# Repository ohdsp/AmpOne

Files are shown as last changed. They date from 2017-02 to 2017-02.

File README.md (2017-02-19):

# [Open Hardware DSP Platform](http://www.ohdsp.org)
## AmpOne
### Revision 1.0

---
# README
### Disclaimer
Copyright Paul Janicki 2017

Licensed under the TAPR Open Hardware License (www.tapr.org/OHL)

This documentation is distributed WITHOUT ANY EXPRESS OR IMPLIED WARRANTY, INCLUDING OF MERCHANTABILITY, SATISFACTORY QUALITY AND FITNESS FOR A PARTICULAR PURPOSE.

### What is this repository?

**Quick summary**

This is Open Hardware DSP Platform AmpOne Module. 

This is a TDA7498 or TDA7492 based Class D amplifier PCB design with up to two ICs fitted allowing for 4 channels of audio.

This repository contains the KiCad design files, manufacturing Gerber/drill files, PDF/drawing files, and relevant documenation for this board.

### What is the project folder structure?
Most folder names are self explanatory. Starting from the top level: \
*AmpOne*
+ *Bill of Materials*  - This contains the bill of materials in CVS, LibreOffice Calc and XML formats
+ *Drawings*  - This contains PDF and SVG outputs of schematic and PCB files
+ *Gerbers* - This contains the PCB Gerbers and drill drawings for manufacture, there is also a zip file ready to send to most manufacturers
+ *KiCad* - This contains the original KiCad schematic and PCB design files
+ *Pick-Place and Stencil* - This contains the pick and place file for automated placement of PCB components and the pasate/stencil layer to make a solder paste stencil 

### How do I get set up?

**Summary of set up**

1. Set your self up a directory on a local disk, something simple will make life easier (eg C:\Electronics on Windows as used here), but anywhere will do just fine.
2. Download the Kicad-Libs from [https://github.com/ohdsp/KiCad-Libs](https://github.com/ohdsp/KiCad-Libs) and place in C:\Electronics\Kicad-Libs (or your chosen folder) 
3. Create a OHDSP subdirectory in C:\Electronics (so C:\Electronics\OHDSP)
3. Download this project to C:\Electronics\OHDSP\AmpOne
4. Fire up Kicad
5. Open the main project file C:\Electronics\OHDSP\AmpOne\KiCad\AmpOne.pro
6. (Optional) Setup Pcbnew component library as below.
7. Do as you wish with the project, just keep it under TAPR Open Hardware License

Make sure your git setup doesn't exclude files used in the project (like .LIB files) or things may go wrong down the line.

**KiCad Library Configuration**

Note that you need to setup a Pcbnew library, but the eeschema libraries should work without any changes if you followed the instructions above.

To setup Pcbnew libraries:

In Pcbnew go to Preferences -> Footprint Libraries Manager. Under Global Libraries tab in the top list check if there is a nickname "MyKiCadLibs-Footprints" (usually at the end of the list). If there is but it points to the wrong place then change the Library Path to point to MyKiCadLibs-Footprints (eg C:\Electronics\KiCad-Libs\MyKiCadLibs-Footprints.pretty) folder for your setup. If this is missing you can use "Append with Wizard", choose "Files on my computer", click next, browse to library location (eg C:\Electronics\KiCad-Libs\MyKiCadLibs-Footprints.pretty) and select the folder MyKiCadLibs-Footprints.pretty, click next, check the Status column states OK and the Format is KiCad (if not re-download the library) and click next, then select "To global library configuration..." and click Finish.

To setup eeschema component libraries:
Either from KiCad project window go to Tools -> Run Library Editor OR under eeschema, go to Tools -> Library Editor. Then Preferences -> Component Libraries.

The top section "Component Library Files" should ideally contain only two libraries, the "power" library that ships with KiCad and "MyKiCadLibs-Lib" available from above. To setup MyKiCadLibs-Lib as a relative path under the "User defined search path" click add. Browse to the location of KiCad-Libs you download above (eg C:\Electronics\KiCad-Libs) and click "Select Folder". Say yes to add a relative path. Under component library files click add, browse to the KiCad-libs again (eg C:\Electronics\KiCad-Libs), select file "MyKiCadLibs-Lib.lib" and click open. MyKiCadLibs-lib should appear in the component library list with no path as it will be using the user defined search path set in the box below.

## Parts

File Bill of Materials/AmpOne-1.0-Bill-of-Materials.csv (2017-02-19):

Reference | Quantity | Footprint | Value | Voltage | Type | Description | Tolerance | Size | Power | Current
C101 C301 C325 C331 C357 | 5 | CAP-TH-D12.5mmP5mm | 560u | '63V | ' | '560uF 63V High ripple current long life, eg Panasonic FR EEUFR1J561L | ' | 'Pitch 5mm, Diameter 12.5mm | ' | '
C102 C302 C326 C332 C358 | 5 | SMD-0805 | 4u7 | '50V | 'X5R | 'Ceramic capacitor | '10% | '0805 | ' | '
C103 C303 C306 C313 C321 C323 C324 C327 C330 C333 C335 C339 C346 C354 C356 C359 C362 | 17 | SMD-0805 | 100n | '50V | 'X7R | 'Ceramic capacitor | '10% | '0805 | ' | '
C203 C205 C210 C212 C217 C219 C224 C226 | 8 | CAP_TH_5mm_W3.5mm | 100n | '63V | 'MKT | 'Polyester film capacitor | '5% | '5mm | ' | '
C202 C204 C206 C209 C211 C213 C216 C218 C220 C223 C225 C227 | 12 | SMD-0805 | 1n | '50V | 'C0G | 'Ceramic capacitor | '5% | '0805 | ' | '
C201 C207 C208 C214 C215 C221 C222 C228 | 8 | CAP-TH-D6.3mmP2.5mm | 10u | '63V | ' | 'High quality capacitor, eg Panasonic FC | ' | 'Pitch 2.5mm, Diameter 6.3mm | ' | '
C304 C305 C307 C308 C309 C310 C312 C316 C317 C318 C319 C320 C328 C329 C334 C338 C340 C341 C342 C343 C345 C349 C350 C351 C352 C353 C360 C361 | 28 | CAP_TH_P5mm_W3.5mm_L7.3mm | 220n | '100V | 'MKT | 'Epcos B32529C1224 or Kemet R82EC3220Z370J – See schematic for detailed part information for TDA7492/TDA7498/TDA7498E | '5% | 'Size | ' | '
C311 C315 C344 C348 | 4 | CAP_TH_5mm | 330p | '1kV | 'FKP | 'Wima FKP2O103301D00J | '5% | '5mm | ' | '
C314 C322 C347 C355 | 4 | SMD-0805 | 10u | '10V | 'X7R | 'Ceramic capacitor | '10% | '0805 | ' | '
C336 C337 | 2 | SMD-0805 | 2u2 | '10v | 'X5R | 'Ceramic capacitor | '20% | '0805 | ' | '
D301 | 1 | DIODE-SOD-123 | MMSZ5225BT1G | '3V | ' | 'SOD-123 Zener Diode | ' | ' | '500mW | '
L301 L302 L303 L304 L305 L306 L307 L308 | 8 | IND-TH-PCV-0-223-10L | PCV-0-223-10L | ' | ' | 'Coilcraft PCV-0-223-10L - See schematic for detailed part information for TDA7492/TDA7498/TDA7498E | ' | 'Size | ' | '13A
P201 | 1 | CONN_DIL_2X10_BOX_1MM | CONN_02X10 | ' | ' | '2x10 2.54mm pitch box header | ' | ' | ' | '
P104 P301 P302 P306 P307 | 5 | CONN-SCREW-2WAY-7.5mm-7.62mm | CONN_2x1 | ' | ' | '7.5mm/7.62mm Pitch 2 Way Screw Terminal | ' | ' | ' | '
P303 P304 P305 P308 P309 P310 P311 | 7 | CONN_SIL_2_1MM | CONN_2x1 | ' | ' | '2x1 Pin Header 2.54mm | ' | ' | ' | '
R202 R203 R206 R207 R210 R211 R214 R215 | 8 | SMD-1206 | 100k | ' | ' | 'MELF0204 1% =>250mW or 1206 1% =>250mW | '1% | '1206 | '250mW | '
R201 R204 R205 R208 R209 R212 R213 R216 | 8 | SMD-1206 | 100 | ' | ' | 'MELF0204 1% =>250mW or 1206 1% =>250mW | '1% | '1206 | '250mW | '
R301 R303 R307 R309 R317 R319 R323 R324 | 8 | SMD_MELF_0207 | 8R2 | ' | ' | 'High Power 1W MELF 0207 | '5% | 'Axial | '1W | '
R302 R306 R318 R322 | 4 | SMD_MELF_0207 | 22 | ' | ' | 'High Power 1W MELF 0207 | '5% | 'Axial | '1W | '
R304 R305 R320 R321 | 4 | SMD-0805 | 10k | ' | ' | 'Thick or thin film resistor | '1% | '0805 | '100mW | '
R308 | 1 | SMD-0805 | 39k | ' | ' | 'Thick or thin film resistor | '1% | '0805 | '100mW | '
R310 | 1 | SMD-2512 | 1k8 | ' | ' | 'High Power 2512 Resistor | '1% | '2512 | '2W | '
R311 | 1 | SMD-0805 | 0 | ' | ' | 'Thick or thin film resistor | '1% | '0805 | '100mW | '
R312 | 1 | SMD-0805 | 47k | ' | ' | 'Thick or thin film resistor | '1% | '0805 | '100mW | '
R313 R315 | 2 | SMD-0805 | 1k | ' | ' | 'Thick or thin film resistor | '1% | '0805 | '100mW | '
R314 | 1 | SMD-0805 | 220k | ' | ' | 'Thick or thin film resistor | '1% | '0805 | '100mW | '
R316 | 1 | SMD-0805 | 33 | ' | ' | 'Thick or thin film resistor | '1% | '0805 | '100mW | '
U301 U302 | 2 | IC-PowerSSO-36-EPU | TDA7498 | ' | ' | 'TDA7492/TDA7498 - See schematic for details | ' | ' | ' | '

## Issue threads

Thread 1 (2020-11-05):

KiCad version 5

tamasharasztosi, 2020-11-05:
Hello!
Great work!
Do you think it's possible or not to convert this project into new KiCad 5?
I have problems with the schematic symbols when I open it.

Thank you!

ohdsp, 2020-11-08:
Hi,

Yes they can all be converted, I still do it, however with 5.1.x versions as soon as you open the project file (v4) it seems to remove all the library information (LibDir=...) from the .pro file and save it with it missing.

When you when try and open the schematic it cannot find any symbols to convert it to a v5 project with. Seems to be because the latest versions put the library location in a separate sym-lib-table file.

Last project I converted I ended up opening the project files in notepad++ and re-adding the library information, which allowed it to convert properly.

This project won't be touched by me for a while, I have all the parts to build several up but haven't got around to it yet. PCB needs an update as some of the filter resistors should be 5W through holes and not SMD parts.

Cheers.

________________________________
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

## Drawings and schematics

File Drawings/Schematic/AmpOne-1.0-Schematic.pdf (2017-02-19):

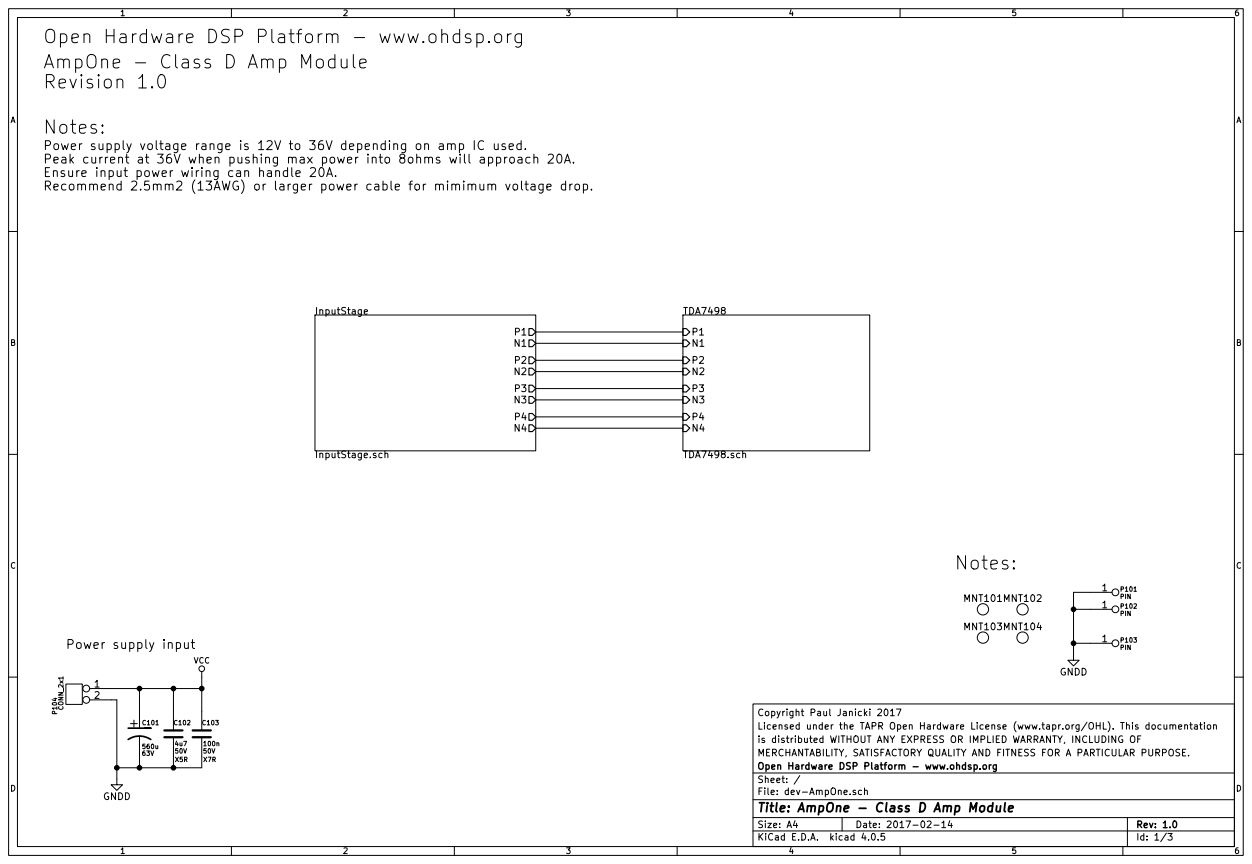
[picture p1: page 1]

Open Hardware DSP Platform - www.ohdsp.org
AmpOne - Class D Amp Module
Revision 1.0

Notes:
Power supply voltage range is 12V to 36V depending on amp IC used.
Peak current at 36V when pushing max power into 8ohms will approach 20A.
Ensure input power wiring can handle 20A.
Recommend 2.5mm2 (13AWG) or larger power cable for mimimum voltage drop.

Copyright Paul Janicki 2017
Licensed under the TAPR Open Hardware License (www.tapr.org/OHL). This documentation
is distributed WITHOUT ANY EXPRESS OR IMPLIED WARRANTY, INCLUDING OF
MERCHANTABILITY, SATISFACTORY QUALITY AND FITNESS FOR A PARTICULAR PURPOSE.
File: dev-AmpOne.sch Sheet: / Open Hardware DSP Platform - www.ohdsp.org

Id: 1/3 Title: AmpOne - Class D Amp Module

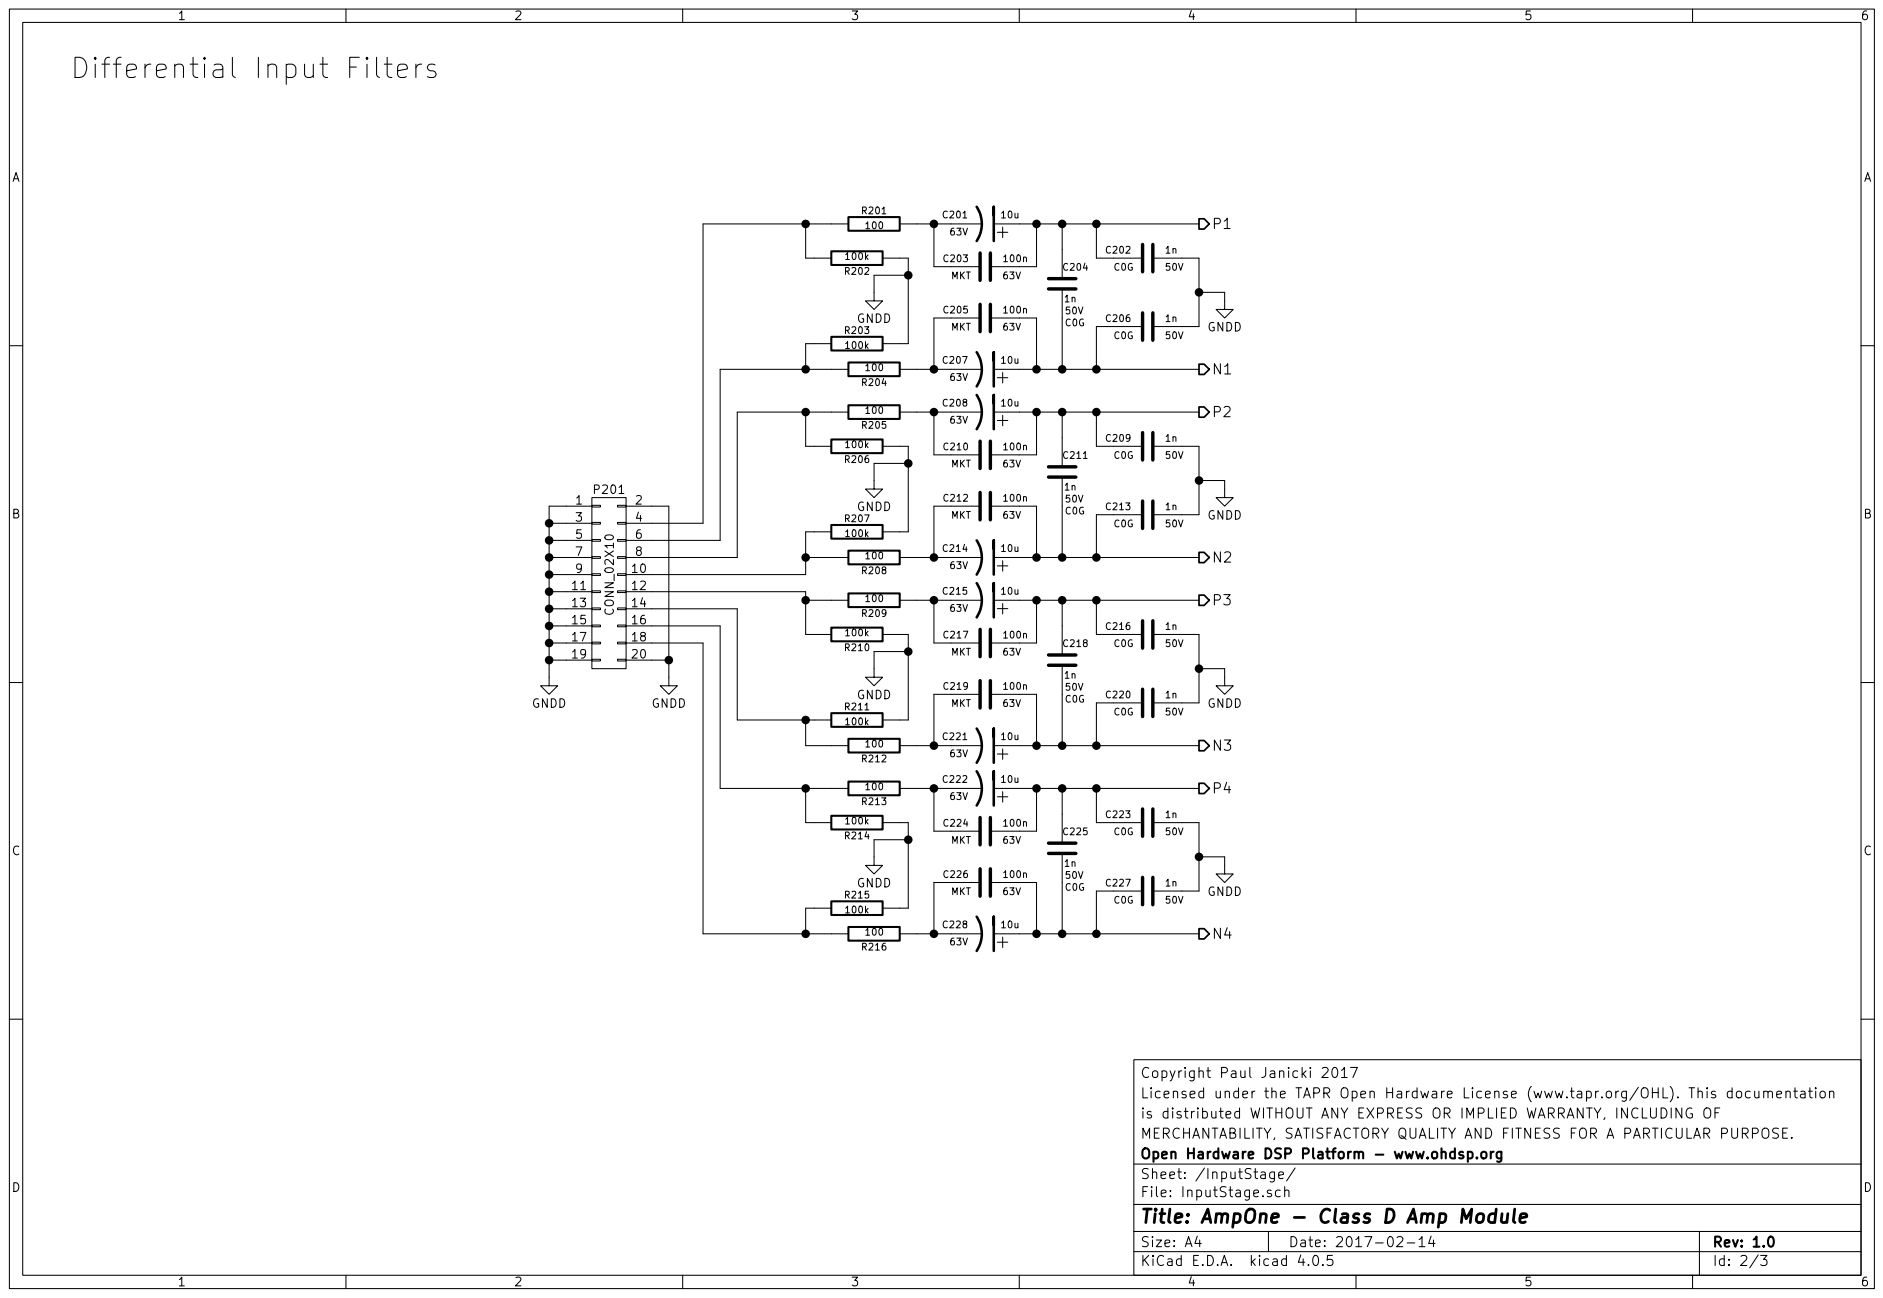
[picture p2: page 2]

9 | 10
11 | 12
13 | 14
15 | 16
17 | 18

Copyright Paul Janicki 2017
Licensed under the TAPR Open Hardware License (www.tapr.org/OHL). This documentation
is distributed WITHOUT ANY EXPRESS OR IMPLIED WARRANTY, INCLUDING OF
MERCHANTABILITY, SATISFACTORY QUALITY AND FITNESS FOR A PARTICULAR PURPOSE.
Open Hardware DSP Platform - www.ohdsp.org
Sheet: /InputStage/
File: InputStage.sch
Id: 2/3 Title: AmpOne - Class D Amp Module

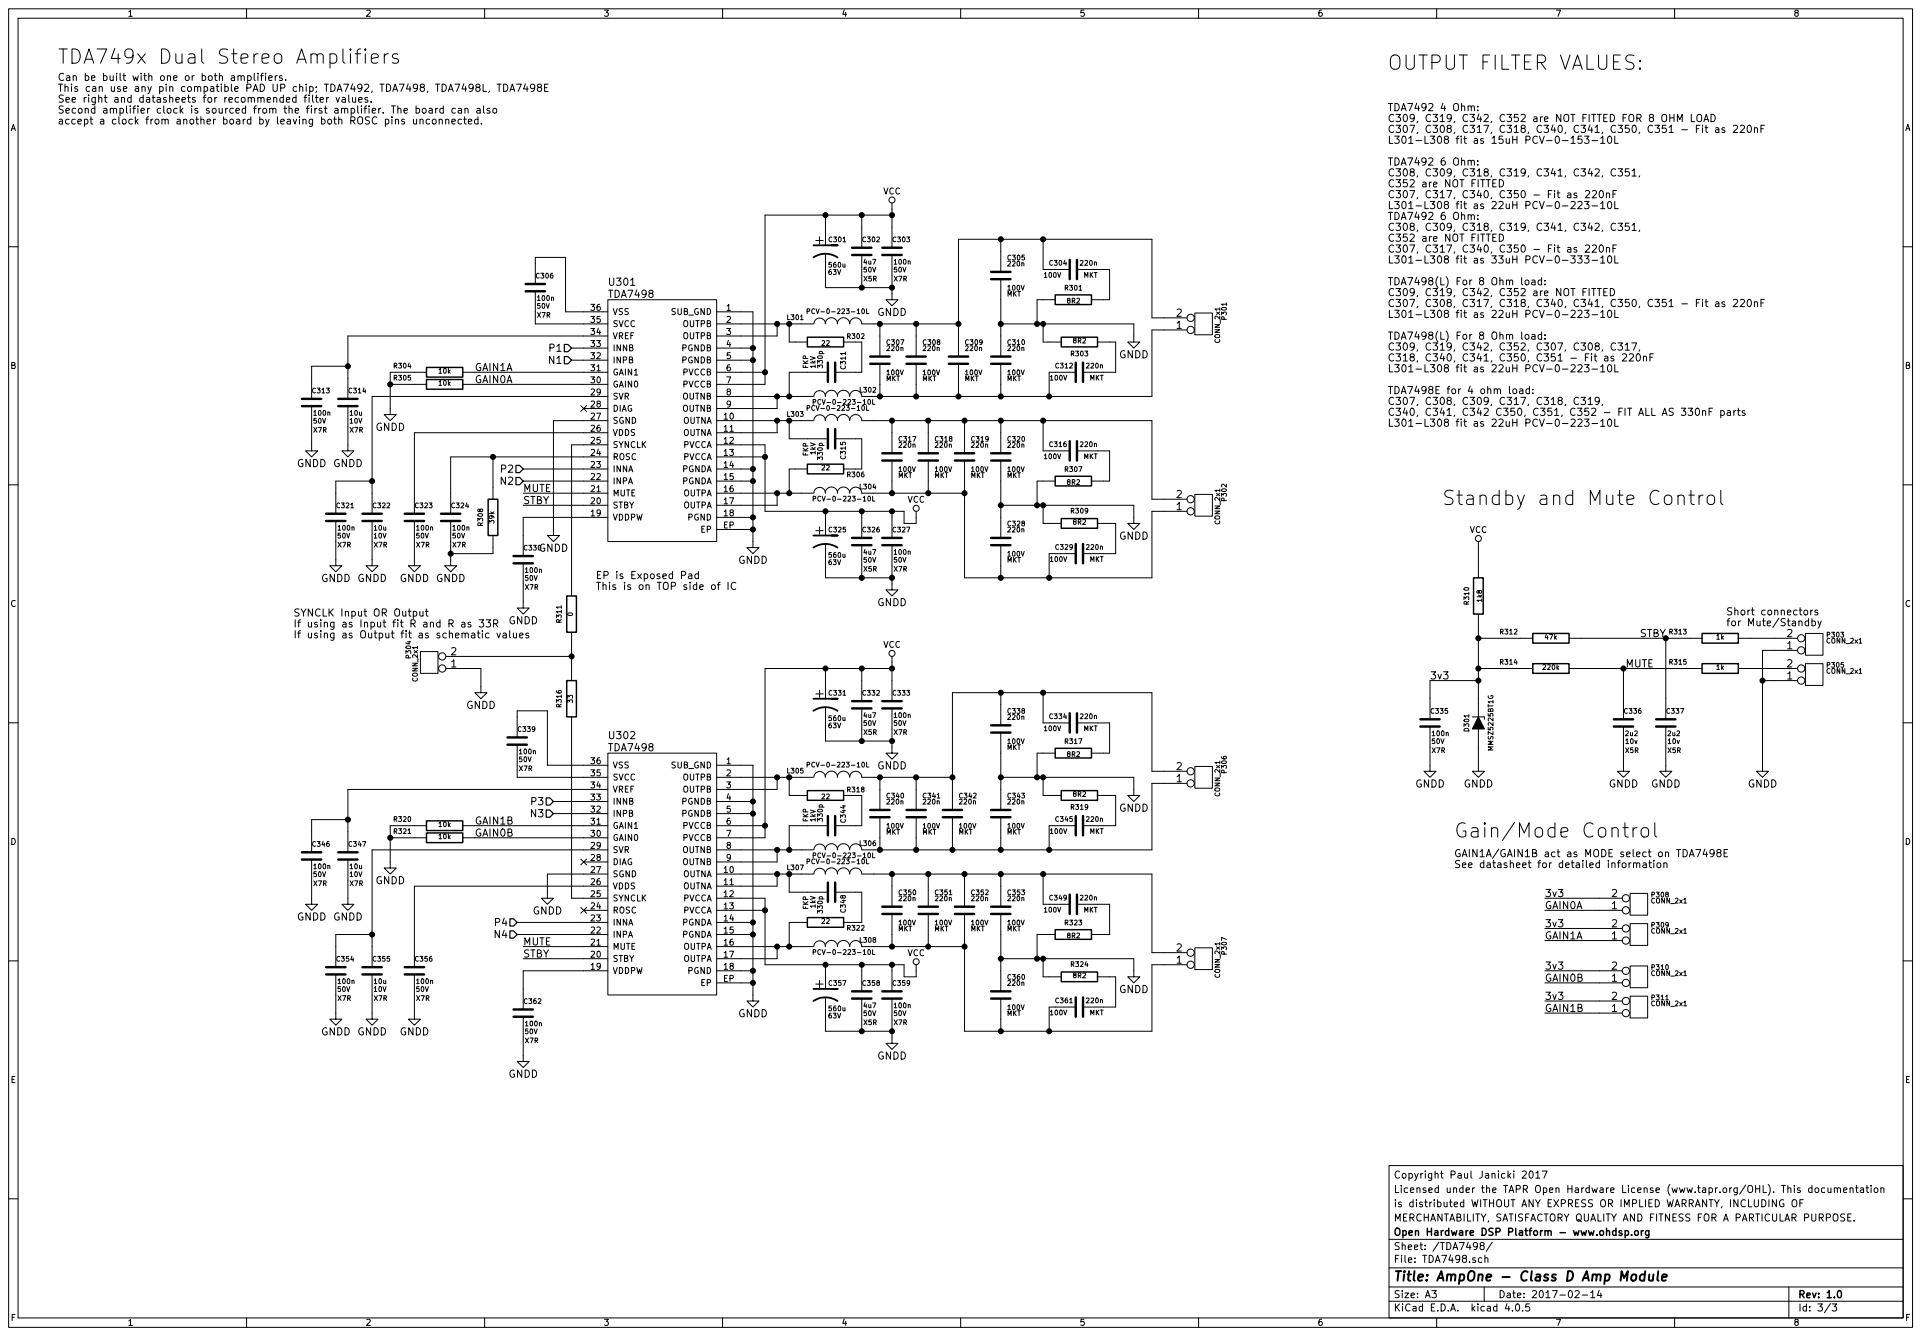
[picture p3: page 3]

Can be built with one or both amplifiers.
This can use any pin compatible PAD UP chip; TDA7492, TDA7498, TDA7498L, TDA7498E
See right and datasheets for recommended filter values.
Second amplifier clock is sourced from the first amplifier. The board can also
accept a clock from another board by leaving both ROSC pins unconnected.

TDA7492 4 Ohm:
C309, C319, C342, C352 are NOT FITTED FOR 8 OHM LOAD
C307, C308, C317, C318, C340, C341, C350, C351 - Fit as 220nF
L301-L308 fit as 15uH PCV-0-153-10L
TDA7492 6 Ohm:
C352 are NOT FITTED
C307, C317, C340, C350 - Fit as 220nF
L301-L308 fit as 22uH PCV-0-223-10L
L301-L308 fit as 33uH PCV-0-333-10L
TDA7498(L) For 8 Ohm load:
C309, C319, C342, C352 are NOT FITTED
C318, C340, C341, C350, C351 - Fit as 220nF
L301-L308 fit as 22uH PCV-0-223-10L TDA7498E for 4 ohm load: C307, C308, C309, C317, C318, C319,

C340, C341, C342 C350, C351, C352 - FIT ALL AS 330nF parts

INNA 23
INPA 22

EP is Exposed Pad
This is on TOP side of IC

If using as Input fit R and R as 33R
If using as Output fit as schematic values

GAIN1A/GAIN1B act as MODE select on TDA7498E

Copyright Paul Janicki 2017
Licensed under the TAPR Open Hardware License (www.tapr.org/OHL). This documentation
is distributed WITHOUT ANY EXPRESS OR IMPLIED WARRANTY, INCLUDING OF
MERCHANTABILITY, SATISFACTORY QUALITY AND FITNESS FOR A PARTICULAR PURPOSE.
File: TDA7498.sch Sheet: /TDA7498/ Open Hardware DSP Platform - www.ohdsp.org

Id: 3/3 Title: AmpOne - Class D Amp Module

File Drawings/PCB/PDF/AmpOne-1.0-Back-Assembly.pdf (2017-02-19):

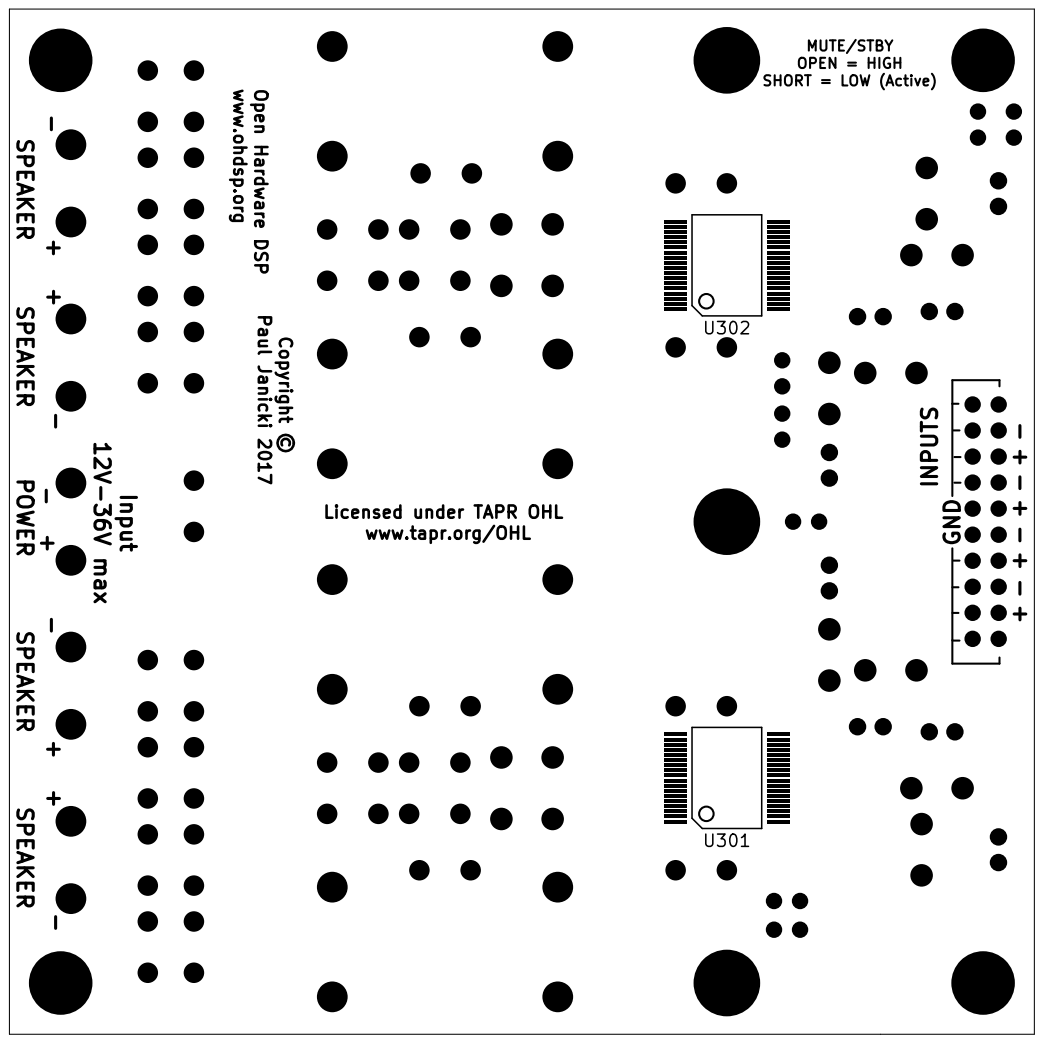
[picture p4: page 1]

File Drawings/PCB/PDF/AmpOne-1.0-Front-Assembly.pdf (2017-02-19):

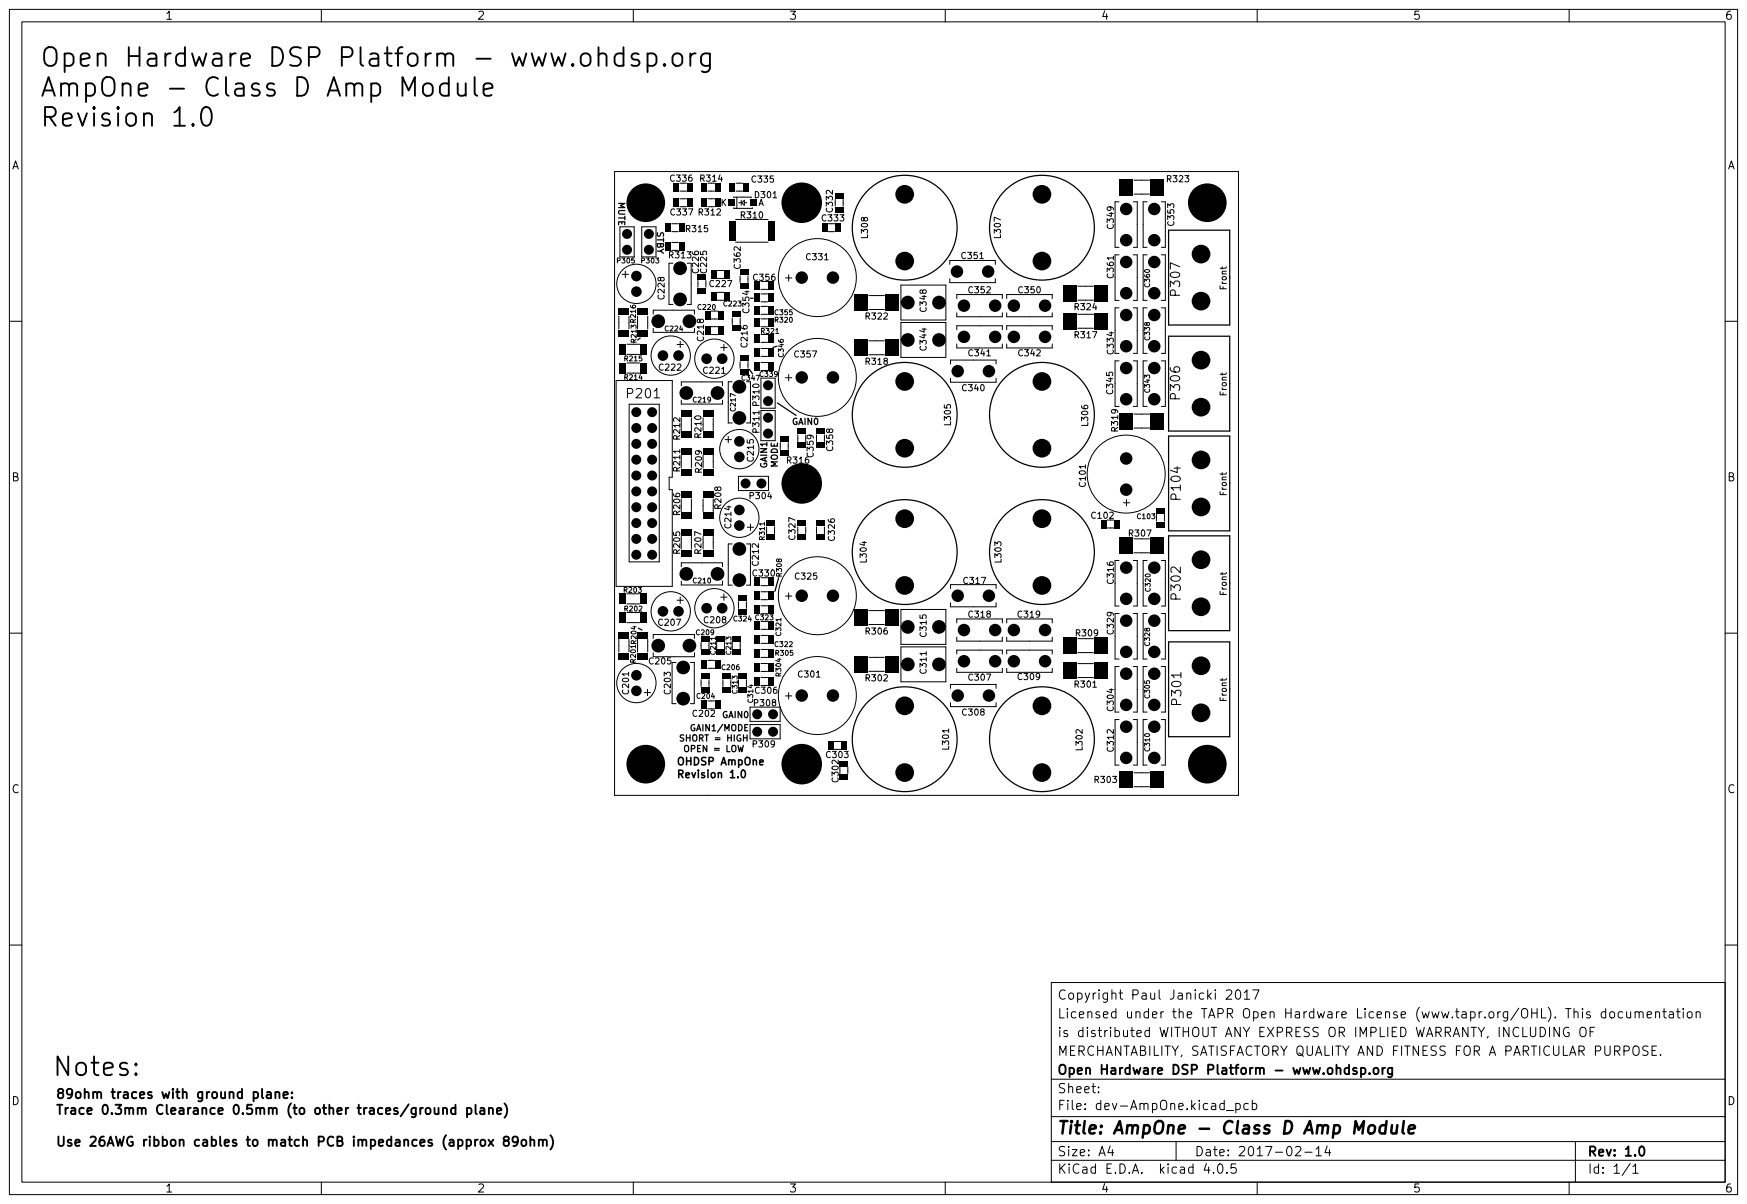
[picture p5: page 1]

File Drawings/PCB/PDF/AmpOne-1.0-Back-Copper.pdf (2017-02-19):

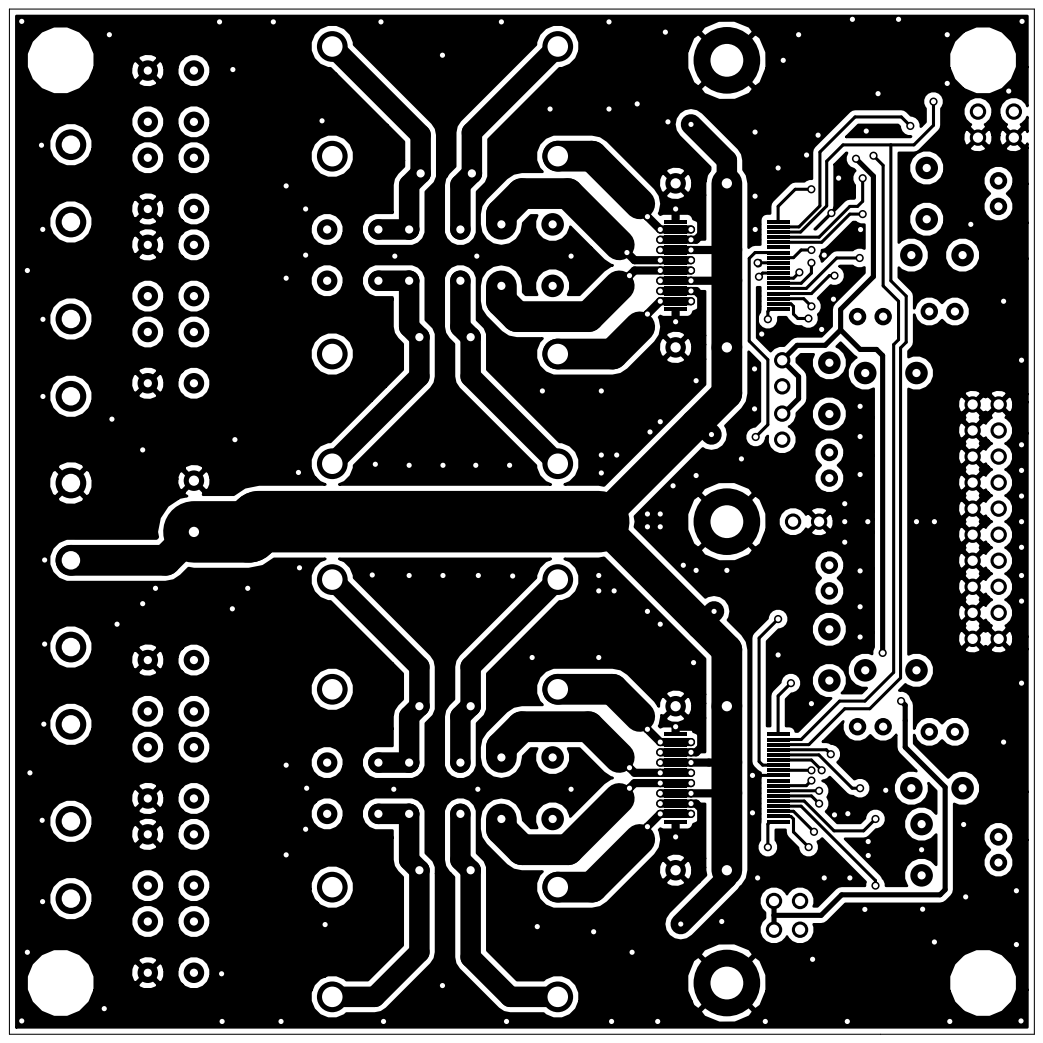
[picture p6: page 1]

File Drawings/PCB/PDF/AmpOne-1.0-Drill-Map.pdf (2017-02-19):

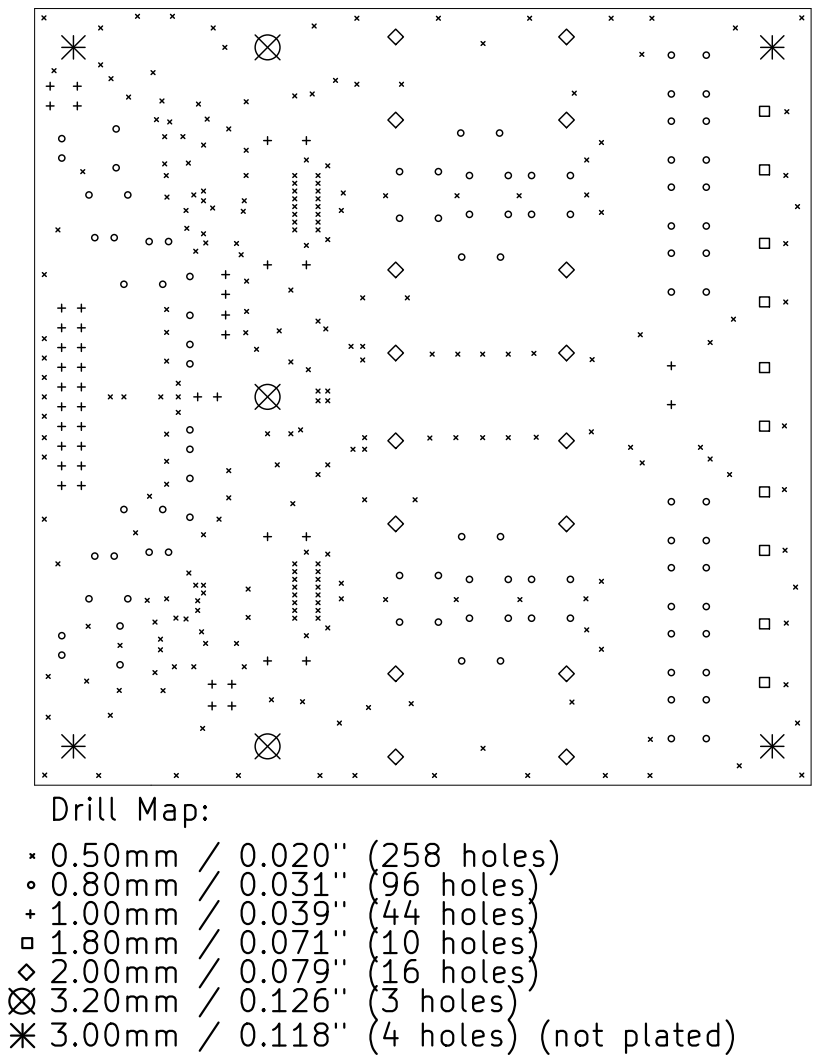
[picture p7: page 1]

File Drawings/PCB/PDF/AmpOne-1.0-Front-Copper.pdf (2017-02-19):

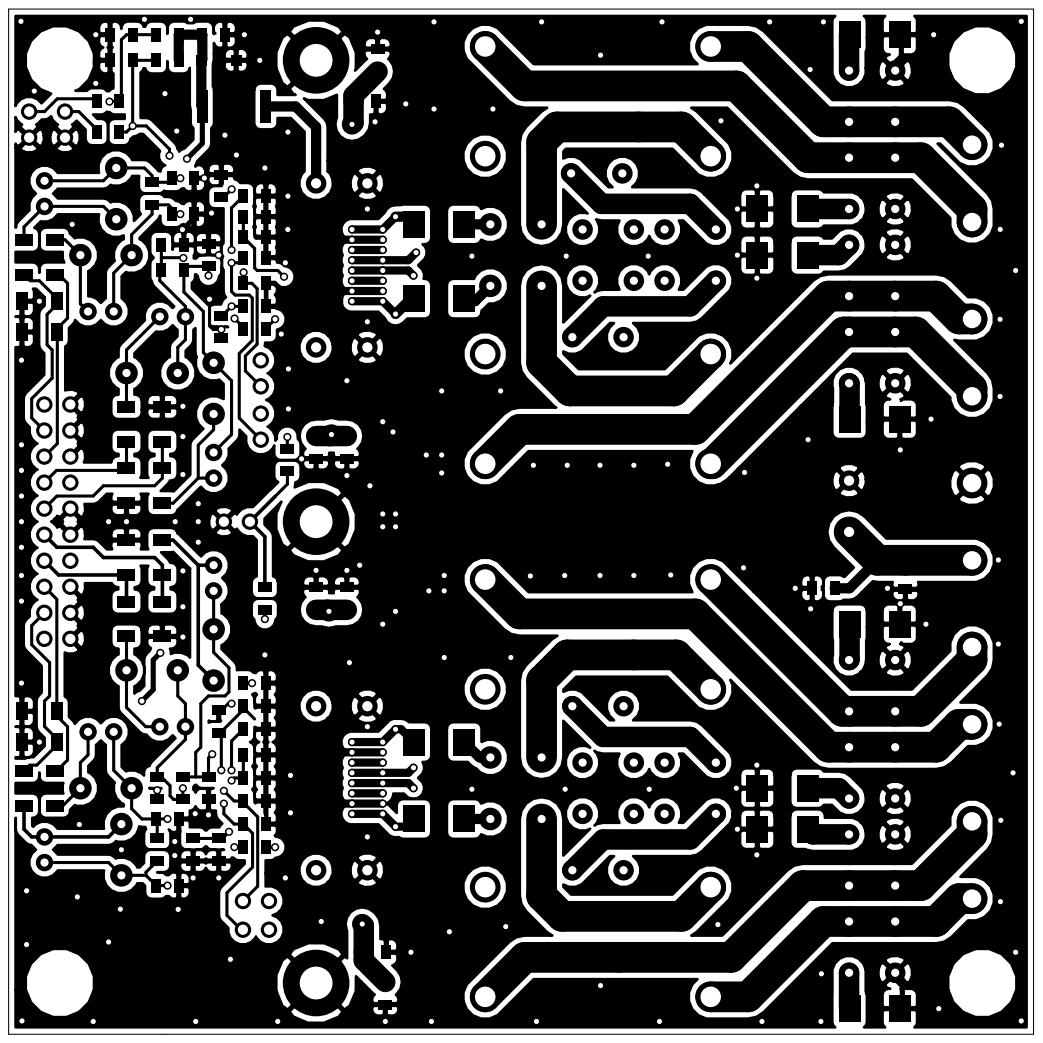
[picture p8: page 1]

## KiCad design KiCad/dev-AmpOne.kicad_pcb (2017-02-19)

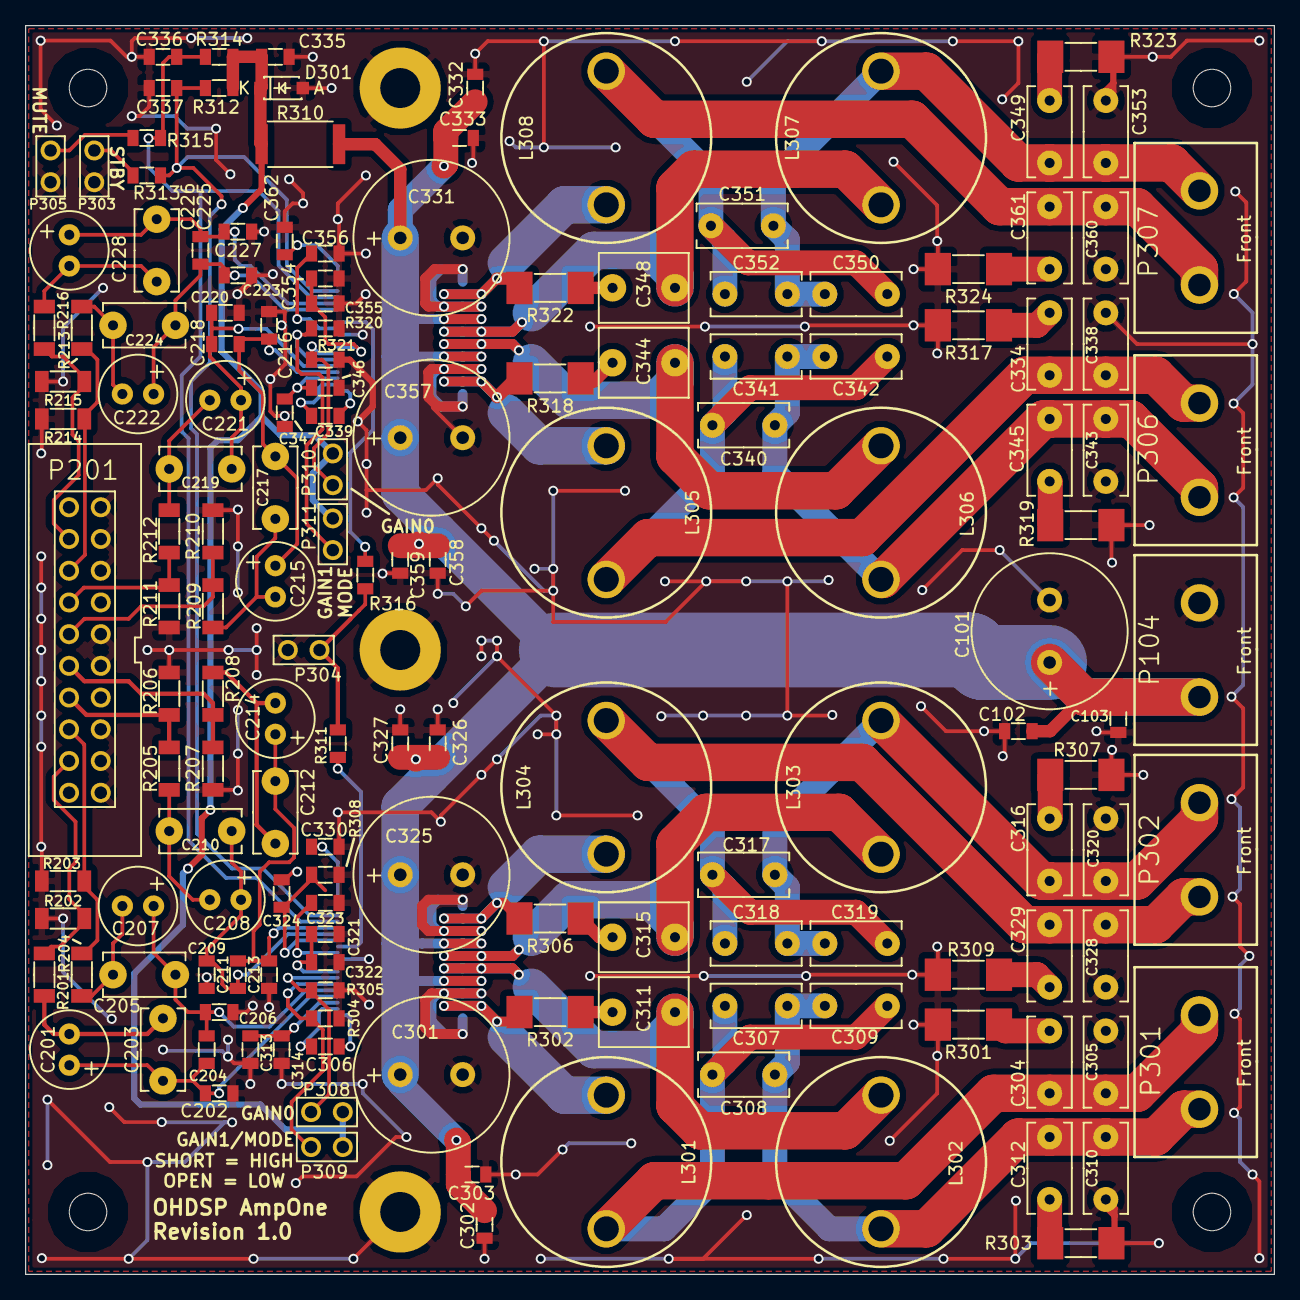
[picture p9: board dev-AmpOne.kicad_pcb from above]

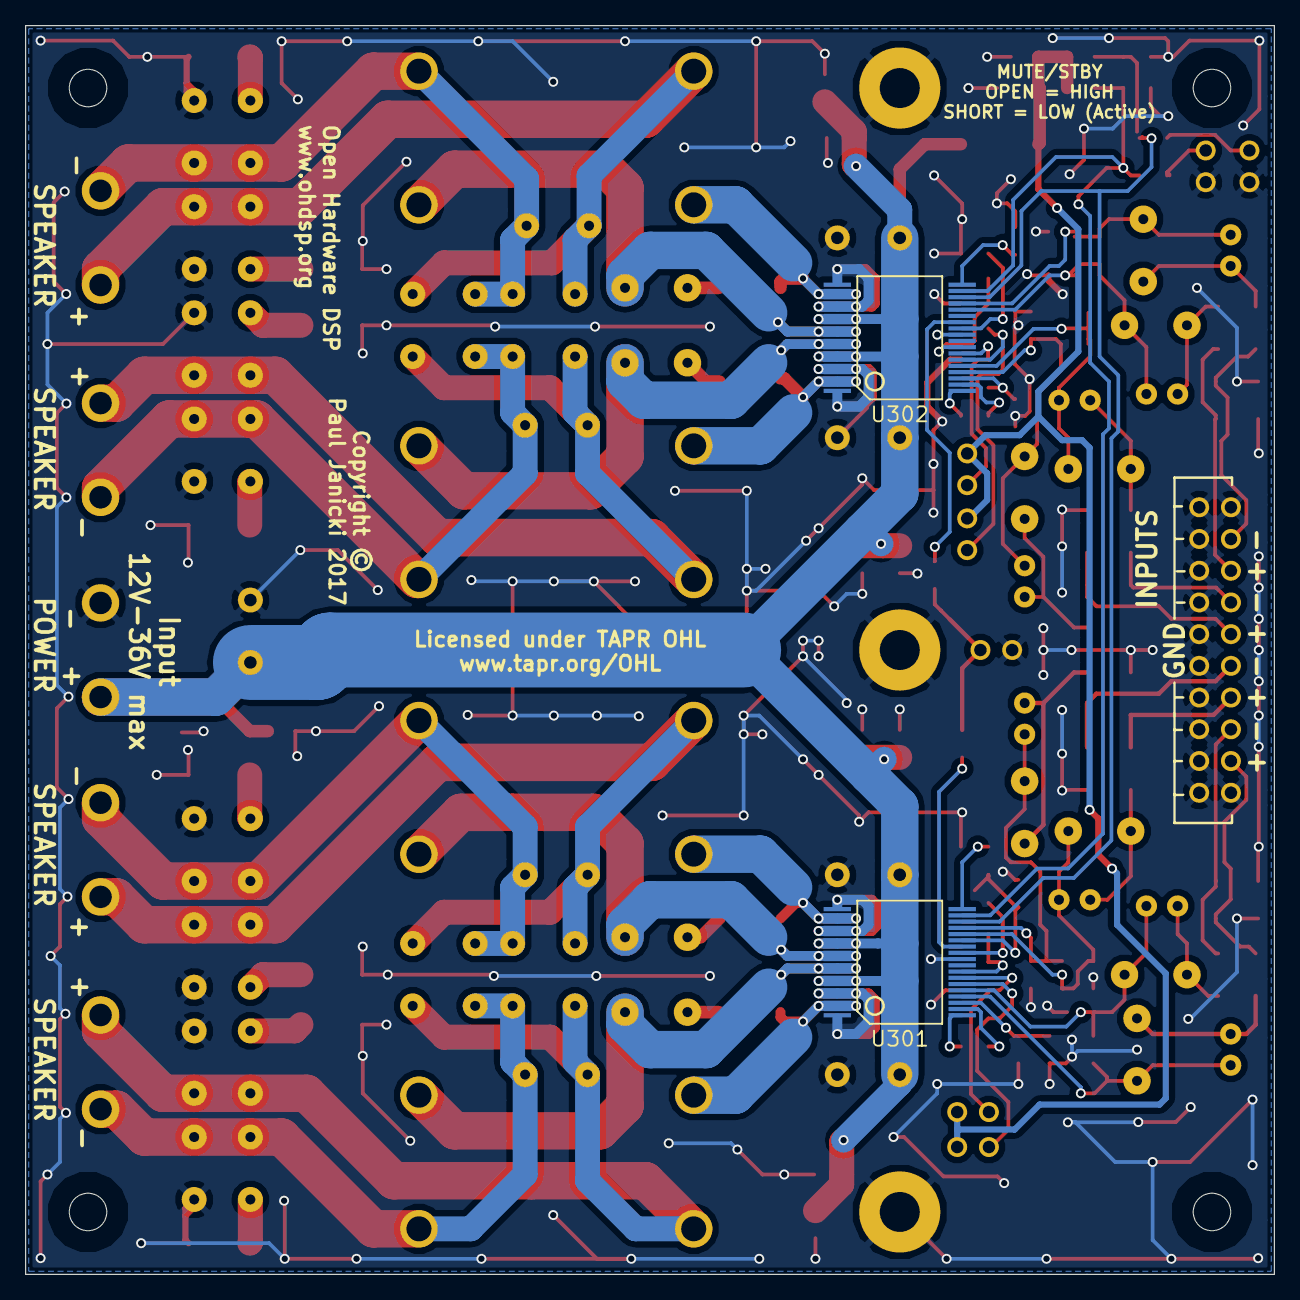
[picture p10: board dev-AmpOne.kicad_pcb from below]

Board: 2 copper layers, 100.0 x 100.0 mm, 164 parts (2 on the bottom side), 79 nets.

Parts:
C101, C301, C325, C331, C357: 560u; CAP-TH-D12.5mmP5mm
C102, C302, C326, C332, C358: 4u7; SMD-0805
C103, C303, C306, C313, C321, C323, C324, C327, C330, C333, C335, C339, C346, C354, C356, C359, C362: 100n; SMD-0805
C201, C207, C208, C214, C215, C221, C222, C228: 10u; CAP-TH-D6.3mmP2.5mm
C202, C204, C206, C209, C211, C213, C216, C218, C220, C223, C225, C227: 1n; SMD-0805
C203, C205, C210, C212, C217, C219, C224, C226: 100n; CAP_TH_5mm_W3.5mm
C304, C305, C307, C308, C309, C310, C312, C316, C317, C318, C319, C320, C328, C329, C334, C338, C340, C341, C342, C343, C345, C349, C350, C351, C352, C353, C360, C361: 220n; CAP_TH_P5mm_W3.5mm_L7.3mm
C311, C315, C344, C348: 330p; CAP_TH_5mm
C314, C322, C347, C355: 10u; SMD-0805
C336, C337: 2u2; SMD-0805
D301: MMSZ5225BT1G; DIODE-SOD-123
L301, L302, L303, L304, L305, L306, L307, L308: PCV-0-223-10L; IND-TH-PCV-0-223-10L
MNT101, MNT102, MNT103, MNT104: MNT_HOLE; MNT_HOLE_3mm
P101, P102, P103: PIN; MNT_HOLE_3mm_PTH
P104, P301, P302, P306, P307: CONN_2x1; CONN-SCREW-2WAY-7.5mm-7.62mm
P201: CONN_02X10; CONN_DIL_2X10_BOX_1MM
P303, P304, P305, P308, P309, P310, P311: CONN_2x1; CONN_SIL_2_1MM
R201, R204, R205, R208, R209, R212, R213, R216: 100; SMD-1206
R202, R203, R206, R207, R210, R211, R214, R215: 100k; SMD-1206
R301, R303, R307, R309, R317, R319, R323, R324: 8R2; SMD_MELF_0207
R302, R306, R318, R322: 22; SMD_MELF_0207
R304, R305, R320, R321: 10k; SMD-0805
R308: 39k; SMD-0805
R310: 1800; SMD-2512
R311: 0; SMD-0805
R312: 47k; SMD-0805
R313, R315: 1k; SMD-0805
R314: 220k; SMD-0805
R316: 33; SMD-0805
U301, U302: TDA7498; IC-PowerSSO-36-EPU

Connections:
/InputStage/N1: C204.2, C205.1, C206.2, C207.1, U301.32
/InputStage/N2: C211.2, C212.1, C213.2, C214.1, U301.22
/InputStage/N3: C218.2, C219.1, C220.2, C221.1, U302.32
/InputStage/N4: C225.2, C226.1, C227.2, C228.1, U302.22
/InputStage/P1: C201.1, C202.2, C203.1, C204.1, U301.33
/InputStage/P2: C208.1, C209.2, C210.1, C211.1, U301.23
/InputStage/P3: C215.1, C216.2, C217.1, C218.1, U302.33
/InputStage/P4: C222.1, C223.2, C224.1, C225.1, U302.23
/TDA7498/3v3: C335.1, D301.2, P308.2, P309.2, P310.2, P311.2, R310.1, R312.1, R314.1
/TDA7498/GAIN0A: P308.1, R305.2, U301.30
/TDA7498/GAIN0B: P310.1, R321.2, U302.30
/TDA7498/GAIN1A: P309.1, R304.2, U301.31
/TDA7498/GAIN1B: P311.1, R320.2, U302.31
/TDA7498/MUTE: C336.1, R314.2, R315.1, U301.21, U302.21
/TDA7498/STBY: C337.1, R312.2, R313.1, U301.20, U302.20
GNDD: C101.2, C102.2, C103.2, C202.1, C206.1, C209.1, C213.1, C216.1, C220.1, C223.1, C227.1, C301.2, C302.2, C303.2, C305.2, C310.1, C313.2, C314.2, C320.2, C321.2, C322.2, C323.2, C324.2, C325.2, C326.2, C327.2, C328.1, C330.2, C331.2, C332.2, C333.2, C335.2, C336.2, C337.2, C338.2, C343.1, C346.2, C347.2, C353.2, C354.2, C355.2, C356.2, C357.2, C358.2, C359.2, C360.1, C362.2, D301.1, P101.1, P102.1, P103.1, P104.2, P201.1, P201.2, P201.3, P201.5, P201.7, P201.9, P201.11, P201.13, P201.15, P201.17, P201.19, P201.20, P303.1, P304.1, P305.1, R202.2, R203.2, R206.2, R207.2, R210.2, R211.2, R214.2, R215.2, R301.2, R303.2, R304.1, R305.1, R307.2, R308.1, R309.2, R317.2, R319.2, R320.1, R321.1, R323.2, R324.2, U301.1, U301.4, U301.5, U301.14, U301.15, U301.18, U301.27, U302.1, U302.4, U302.5, U302.14, U302.15, U302.18, U302.27
unnamed: C201.2, C203.2, R201.1
unnamed: C205.2, C207.2, R204.1
unnamed: C208.2, C210.2, R205.1
unnamed: C212.2, C214.2, R208.1
unnamed: C215.2, C217.2, R209.1
unnamed: C219.2, C221.2, R212.1
unnamed: C222.2, C224.2, R213.1
unnamed: C226.2, C228.2, R216.1
unnamed: C304.1, C305.1, C307.1, C308.1, C309.1, L301.2, P301.2
unnamed: C304.2, R301.1
unnamed: C306.1, U301.36
unnamed: C306.2, U301.35
unnamed: C307.2, C308.2, C309.2, C310.2, C312.1, L302.2, P301.1
unnamed: C311.1, R302.1
unnamed: C311.2, L302.1, U301.8, U301.9
unnamed: C312.2, R303.1
unnamed: C313.1, C314.1, U301.34
unnamed: C315.1, R306.1
unnamed: C315.2, L303.1, U301.10, U301.11
unnamed: C316.1, C317.1, C318.1, C319.1, C320.1, L303.2, P302.2
unnamed: C316.2, R307.1
unnamed: C317.2, C318.2, C319.2, C328.2, C329.1, L304.2, P302.1
unnamed: C321.1, C322.1, U301.29
unnamed: C323.1, U301.26
unnamed: C324.1, R308.2, U301.24
unnamed: C329.2, R309.1
unnamed: C330.1, U301.19
unnamed: C334.1, C338.1, C340.1, C341.1, C342.1, L305.2, P306.2
unnamed: C334.2, R317.1
unnamed: C339.1, U302.36
unnamed: C339.2, U302.35
unnamed: C340.2, C341.2, C342.2, C343.2, C345.1, L306.2, P306.1
unnamed: C344.1, R318.1
unnamed: C344.2, L306.1, U302.8, U302.9
unnamed: C345.2, R319.1
unnamed: C346.1, C347.1, U302.34
unnamed: C348.1, R322.1
unnamed: C348.2, L307.1, U302.10, U302.11
unnamed: C349.1, C350.1, C351.1, C352.1, C353.1, L307.2, P307.2
unnamed: C349.2, R323.1
unnamed: C350.2, C351.2, C352.2, C360.2, C361.1, L308.2, P307.1
unnamed: C354.1, C355.1, U302.29
unnamed: C356.1, U302.26
unnamed: C361.2, R324.1
unnamed: C362.1, U302.19
unnamed: L301.1, R302.2, U301.2, U301.3
unnamed: L304.1, R306.2, U301.16, U301.17
unnamed: L305.1, R318.2, U302.2, U302.3
unnamed: L308.1, R322.2, U302.16, U302.17
unnamed: P201.4, R201.2, R202.1
unnamed: P201.6, R203.1, R204.2
unnamed: P201.8, R205.2, R206.1
unnamed: P201.10, R207.1, R208.2
unnamed: P201.12, R209.2, R210.1
unnamed: P201.14, R211.1, R212.2
unnamed: P201.16, R213.2, R214.1
unnamed: P201.18, R215.1, R216.2
unnamed: P303.2, R313.2
unnamed: P304.2, R311.1, R316.2
unnamed: P305.2, R315.2
unnamed: R311.2, U301.25
unnamed: R316.1, U302.25
VCC: C101.1, C102.1, C103.1, C301.1, C302.1, C303.1, C325.1, C326.1, C327.1, C331.1, C332.1, C333.1, C357.1, C358.1, C359.1, P104.1, R310.2, U301.6, U301.7, U301.12, U301.13, U302.6, U302.7, U302.12, U302.13

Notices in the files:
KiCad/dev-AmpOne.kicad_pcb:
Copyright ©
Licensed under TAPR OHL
